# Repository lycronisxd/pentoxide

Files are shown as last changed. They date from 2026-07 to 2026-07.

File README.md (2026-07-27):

<h1 align="center">
  <picture>
  <source media="(prefers-color-scheme: dark)" srcset="https://github.com/user-attachments/assets/7219ccd8-d57b-41d6-96ce-b18b46f74935">
  <source media="(prefers-color-scheme: light)" srcset="https://github.com/user-attachments/assets/e426a1b6-aba4-4cd7-84bb-a8587f43f761">
  
  </picture>
</h1>

<h3 align="center">
  <picture>
  <source media="(prefers-color-scheme: dark)" srcset="https://github.com/user-attachments/assets/bf6074c8-e379-4ea4-a1d4-aef35d5d1d9c">
  <source media="(prefers-color-scheme: light)" srcset="https://github.com/user-attachments/assets/225eb73b-afd0-433c-afb1-c990a066f6d8">
  
  </picture>
  <div align="center">
    
  
  
  
  
  
  

  </div>
</h3>

<hr>

<!-- main body -->

<h3 align="center">
  <picture>
  <source media="(prefers-color-scheme: dark)" srcset="https://github.com/user-attachments/assets/0eb199f3-a66a-426e-8b88-3ce38c6fcc99">
  <source media="(prefers-color-scheme: light)" srcset="https://github.com/user-attachments/assets/3255cb05-ad44-49c5-b112-34e3b81043f4">
  
  </picture>
  <pre align="left">
pentoxide is an 18-key macro pad designed for creators and developers,
blending design language and function.
<br \>
built on top of QMK firmware with VIA compatibility,
pentoxide supports per-key rgb and a 128x160 1.8 inch lcd.
</pre>
</h3>

<hr>

<h3 align="center">
  <picture>
  <source media="(prefers-color-scheme: dark)" srcset="https://github.com/user-attachments/assets/8696bc60-909f-4c6e-ad67-8837299f265d">
  <source media="(prefers-color-scheme: light)" srcset="https://github.com/user-attachments/assets/cbb11c29-4aa7-4d3f-bdc8-6d2b004aac17">
  
  </picture>
<pre align="left">
{
"microcontroller": "raspberry-pi-rp2040",
"cpu-cores": "dual-core",
"clock-speed": "133-mhz",
"on-board-memory": "264-kb",
"gpio-pins": "30x",
"main-pcb": "pentoxide-mainboard",
"1u-mx-switches": "18x",
"switch-type": "everglide-aqua-king",
"rgb-capability": "y",
"rgb-leds": "18x",
"hotswap-capability": "y",
"kailh-hotswap-sockets": "18x",
"communication-sockets": "22x",
"display-size": "1.8-inch",
"display-resolution": "128x160",
"display-type": "tft-lcd",
"display-controller": "st7735s",
"firmware": "qmk",
"via-compatibility": "y"
}
</pre>
</h3>

<hr>

<h3 align="center">
  <picture>
  <source media="(prefers-color-scheme: dark)" srcset="https://github.com/user-attachments/assets/8fcd9fb2-011e-4284-a5a9-fb2776e90f1c">
  <source media="(prefers-color-scheme: light)" srcset="https://github.com/user-attachments/assets/7539e3ad-ad35-4bb8-8679-a545f65c9159">
  
  </picture>
  board image<br \>
  board image<br \>
  board image<br \>
  board image<br \>
  schematic<br \>
  kicad pcb image<br \>

</h3>

<hr>

<h3 align="center">
  <picture>
    <source media="(prefers-color-scheme: dark)" srcset="https://github.com/user-attachments/assets/2efd42f7-1078-4c4d-a306-e1f4fbedd322">
    <source media="(prefers-color-scheme: light)" srcset="https://github.com/user-attachments/assets/5ac018fb-4700-4111-8b4f-f1ed9c2d6f2b">
    
  </picture>
<pre align="left">
link to the public onshape project.
<a href="https://cad.onshape.com/documents/c17d4654dfdc64fa37b92d7c/w/b8eaedabc024b5a89ea703d7/e/db311653fe3b2444e14a3d99">https://pentoxide.onshape.com</a>
link to repo kicad files.
<a href="https://github.com/lycronisxd/pentoxide/tree/main/pcb">cd /root/pentoxide/pcb</a>
link to repo 3d printing files.
<a href="https://github.com/lycronisxd/pentoxide/tree/main/3dprinting">cd /root/pentoxide/3dprinting</a>
link to thingiverse 3d printing files.
<a href="https://www.thingiverse.com/thing:7385880">https://www.pentoxide.thingiverse.com</a>
</pre>
</h3>

<hr>

<h3 align="center">
  <picture>
  <source media="(prefers-color-scheme: dark)" srcset="https://github.com/user-attachments/assets/4b0244e2-1685-40e0-b2d2-98d43885c8d7">
  <source media="(prefers-color-scheme: light)" srcset="https://github.com/user-attachments/assets/0805ec88-f31b-448b-9def-bbe6aa447988">
  
  </picture>
  <pre align="left">
&lt!DOCTYPE html&gt
  &lthtml lang="en"&gt
    &lthead&gt
      &ltmeta charset="UTF-8"&gt
      &lttitle&gtrelevant links!&lt/title&gt
    &lt/head&gt
  &ltbody&gt
      &lth1&gthey there! below are some links to other projects that you can follow!&lt/h1&gt
      &lthr&gt
      &ltp&gt&lta href="https://github.com/lycronisxd/a-shift"&gt<a href="https://github.com/lycronisxd/a-shift">a-shift</a>&lt/a&gt&lt/p&gt
      &ltp&gt&lta href="https://github.com/lycronisxd/oxide-one"&gt<a href="https://github.com/lycronisxd/oxide-one">oxide-one</a>&lt/a&gt&lt/p&gt
      &ltp&gt&lta href="https://github.com/lycronisxd/ohm"&gt<a href="https://github.com/lycronisxd/ohm">ohm</a>&lt/a&gt&lt/p&gt
      &ltp&gt&lta href="https://github.com/lycronisxd/peroxide"&gt<a href="https://github.com/lycronisxd/peroxide">peroxide</a>&lt/a&gt&lt/p&gt
      &ltp&gt&lta href="https://github.com/lycronisxd/polylactic"&gt<a href="https://github.com/lycronisxd/polylactic">polylactic</a>&lt/a&gt&lt/p&gt
  &lt/body&gt
  &lt!--
  @@@@@@@@@@@@@@@@@@@@@@@@@@@@@@@@@@@@@@@@@@@@@@%#*************************************************#@@
  @@@@@@@@@@@@@@@@@@@@@@@@@@@@@@@@@@@@@@@@@%#%@@=.                    ..*#+         +#*.           =%@
  @@@@@@@@@@@@@@@@@@@@@@@@@@@@@@@@@@@@@@@@%+.=%@=.                    ..--:         *@%.           =%@
  @@@@@#-=+-:::-%@@@@#-:::-*@@@=:#=:::-*@#-...:+=.:+#%%#*-..-*#=. .+##..*#+  .+#%%#*#@%. .:*#%%#=..=%@
  @@@@@*..-#%%+:.+@@-.=%%%=.=%@-..*%%*.:*@#=.=#%=+%@-:.-*@*:.:#@#-#@*...#@* -#@*-::+@@%..+@#:.:+%#:=%@
  @@@@@*.:#@@@@+..%*..====-:.*@-.+@@@%:.+@%+.=%@*%@-   .:%%=  .+%@@:. ..#@*.=@#:.  .*@%.-@%#****%@==%@
  @@@@#-%%-   .+%%.+@%.........#@+.  .%%+ .+@*. =..*@@@@#:.+@@%-...:@@@%:.=@+ -#@@@@= :@#.:#@@@@@@@@@@
  @@@@#-%@%-..+%@+..%@#...+@%-.#@+.  .%%+ .+@#:.++..#@@#-.-%@*:.*@=..#@%:.=@%-.-#%%=. :@%=.-%@@*::#@@@
  @@@@#-%%**%%%*:.  .-#%%%#=. .*#=.  .##+ .:*%%**%%+::::-#@@+:-#@@@#::+%=:+@@@*-:::+*:-@@@#=::::*%@@@@
  @@@@#-%%-                                     +%@@@@@@@@@@@@@@@@@@@@@@@@@@@@@@@@@@@@@@@@@@@@@@@@@@@@
  @@@@#-**-                                     +%@@@@@@@@@@@@@@@@@@@@@@@@@@@@@@@@@@@@@@@@@@@@@@@@@@@@
  @@@@@%%%%%%%%%%%%%%%%%%%%%%%%%%%%%%%%%%%%%%%%%@@@@@@@@@@@@@@@@@@@@@@@@@@@@@@@@@@@@@@@@@@@@@@@@@@@@@@
  --&gt
</pre>
</h3>
  
<hr>

<h3 align="center">

  <picture>
  <source media="(prefers-color-scheme: dark)" srcset="https://github.com/user-attachments/assets/031f2031-ec8b-4581-bf83-9b06f5faa409">
  <source media="(prefers-color-scheme: light)" srcset="https://github.com/user-attachments/assets/4cdb615e-4db5-4dbc-abcc-0074ae9797d5">
  
  </picture>
</h3>

| item no. | part no. | part name | qty. | supplier | unit cost | total cost | notes |
|---|---|---|----:|---|---:|---:|---|
| 1 | PCB-001 | pentoxide-pcb | 1 | jlcpcb | $11.90 | $11.90 | - |
| 2 | PCB-002 | 0805-100nf-cap | 18 | aliexpress | $0.04 | $3.62 | 100 pcs was the smallest i could find. |
| 3 | PCB-003 | 0805-330-res | 1 | aliexpress | $2.64 | $2.64 | - |
| 4 | PCB-004 | sod-123-1n4148w | 18 | aliexpress | $0.02 | $1.53 | 100 pcs was the smallest i could find. |
| 5 | PCB-005 | kailh-hs-socket | 18 | aliexpress | $0.22 | $6.66 | 30 pcs was the smallest i could find. |
| 6 | PCB-006 | sk6812-mini-e-led | 18 | aliexpress | $0.08 | $4.09 | 50 pcs was the smallest i could find. |
| 7 | PCB-007 | 128x160-lcd | 1 | aliexpress | $3.82 | $3.82 | - |
| 8 | PCB-008 | rp2040-pro-micro | 1 | aliexpress | $3.79 | $3.79 | - |
| 9 | SW-001 | mmd-aqua-king | 18 | aliexpress | $0.53 | $15.81 | 30 pcs was the smallest i could find. |
| 10 | SW-002 | cherry-keycap | 18 | aliexpress | $0.30 | $5.91 | 20 pcs was the smallest i could find. |
| 11 | MNT-001 | m4-bolt | 10 | aliexpress | $8.97 | $8.97 | see notes below. |
| 12 | MNT-002 | m2-bolt | 4 | aliexpress | - | - | price included in M4 bolt price. |
| 13 | MNT-003 | m2-nut | 4 | aliexpress | - | - | price included in M4 bolt price. |
| 14 | MNT-004 | m4-insert | 10 | aliexpress | $0.04 | $4.02 | 100 pcs was the smallest i could find. |
| 15 | 3D-001 | pentoxide-plate | 1 | N/A | - | - | custom print / print legion. |
| 16 | 3D-002 | pentoxide-case | 1 | N/A | - | - | custom print / print legion. |

<br />
<b>total cost : 72.76 USD (54.24 GBP)</b>
<hr>

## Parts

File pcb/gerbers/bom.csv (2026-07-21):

Designator | Footprint | Quantity | Value | LCSC Part #
C1, C10, C11, C12, C13, C14, C17, C18, C19, C2, C20, C3, C4, C5, C6, C7, C8, C9 | 805 | 18 | 0.1uF | C14663
D1, D10, D11, D12, D13, D14, D17, D18, D19, D2, D20, D3, D4, D5, D6, D7, D8, D9 | D_SOD-123 | 18 | D_Small | C241939
D21, D22, D23, D24, D25, D26, D27, D28, D29, D30, D31, D32, D33, D34, D37, D38, D39, D40 | LED_SK6812MINI-E_3.2x2.8mm_P1.5mm_ReverseMount | 18 | SK6812MINI-E | C5149201
J2 | PinHeader_2x11_P2.54mm_Vertical | 1 | DNP
R1 | 805 | 1 | 330 | C2907002
SW1, SW10, SW11, SW12, SW13, SW14, SW17, SW18, SW19, SW2, SW20, SW3, SW4, SW5, SW6, SW7, SW8, SW9 | MX-Hotswap-1U | 18 | SW_Push | C49352235

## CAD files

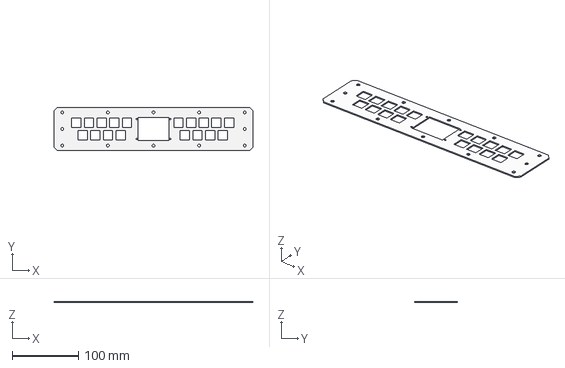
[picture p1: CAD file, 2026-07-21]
3dprinting/plate.step
300.0 x 65.0 x 1.50 mm

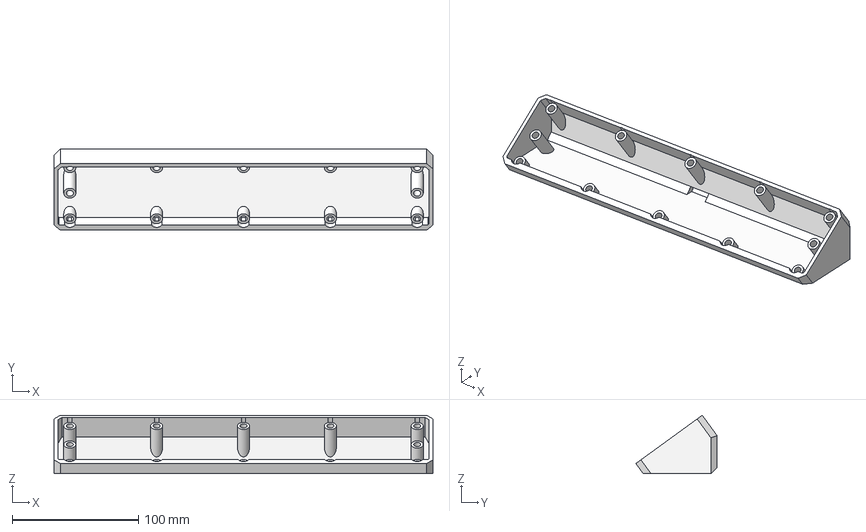
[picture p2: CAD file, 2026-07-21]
3dprinting/case.step
300.0 x 64.3 x 46.3 mm

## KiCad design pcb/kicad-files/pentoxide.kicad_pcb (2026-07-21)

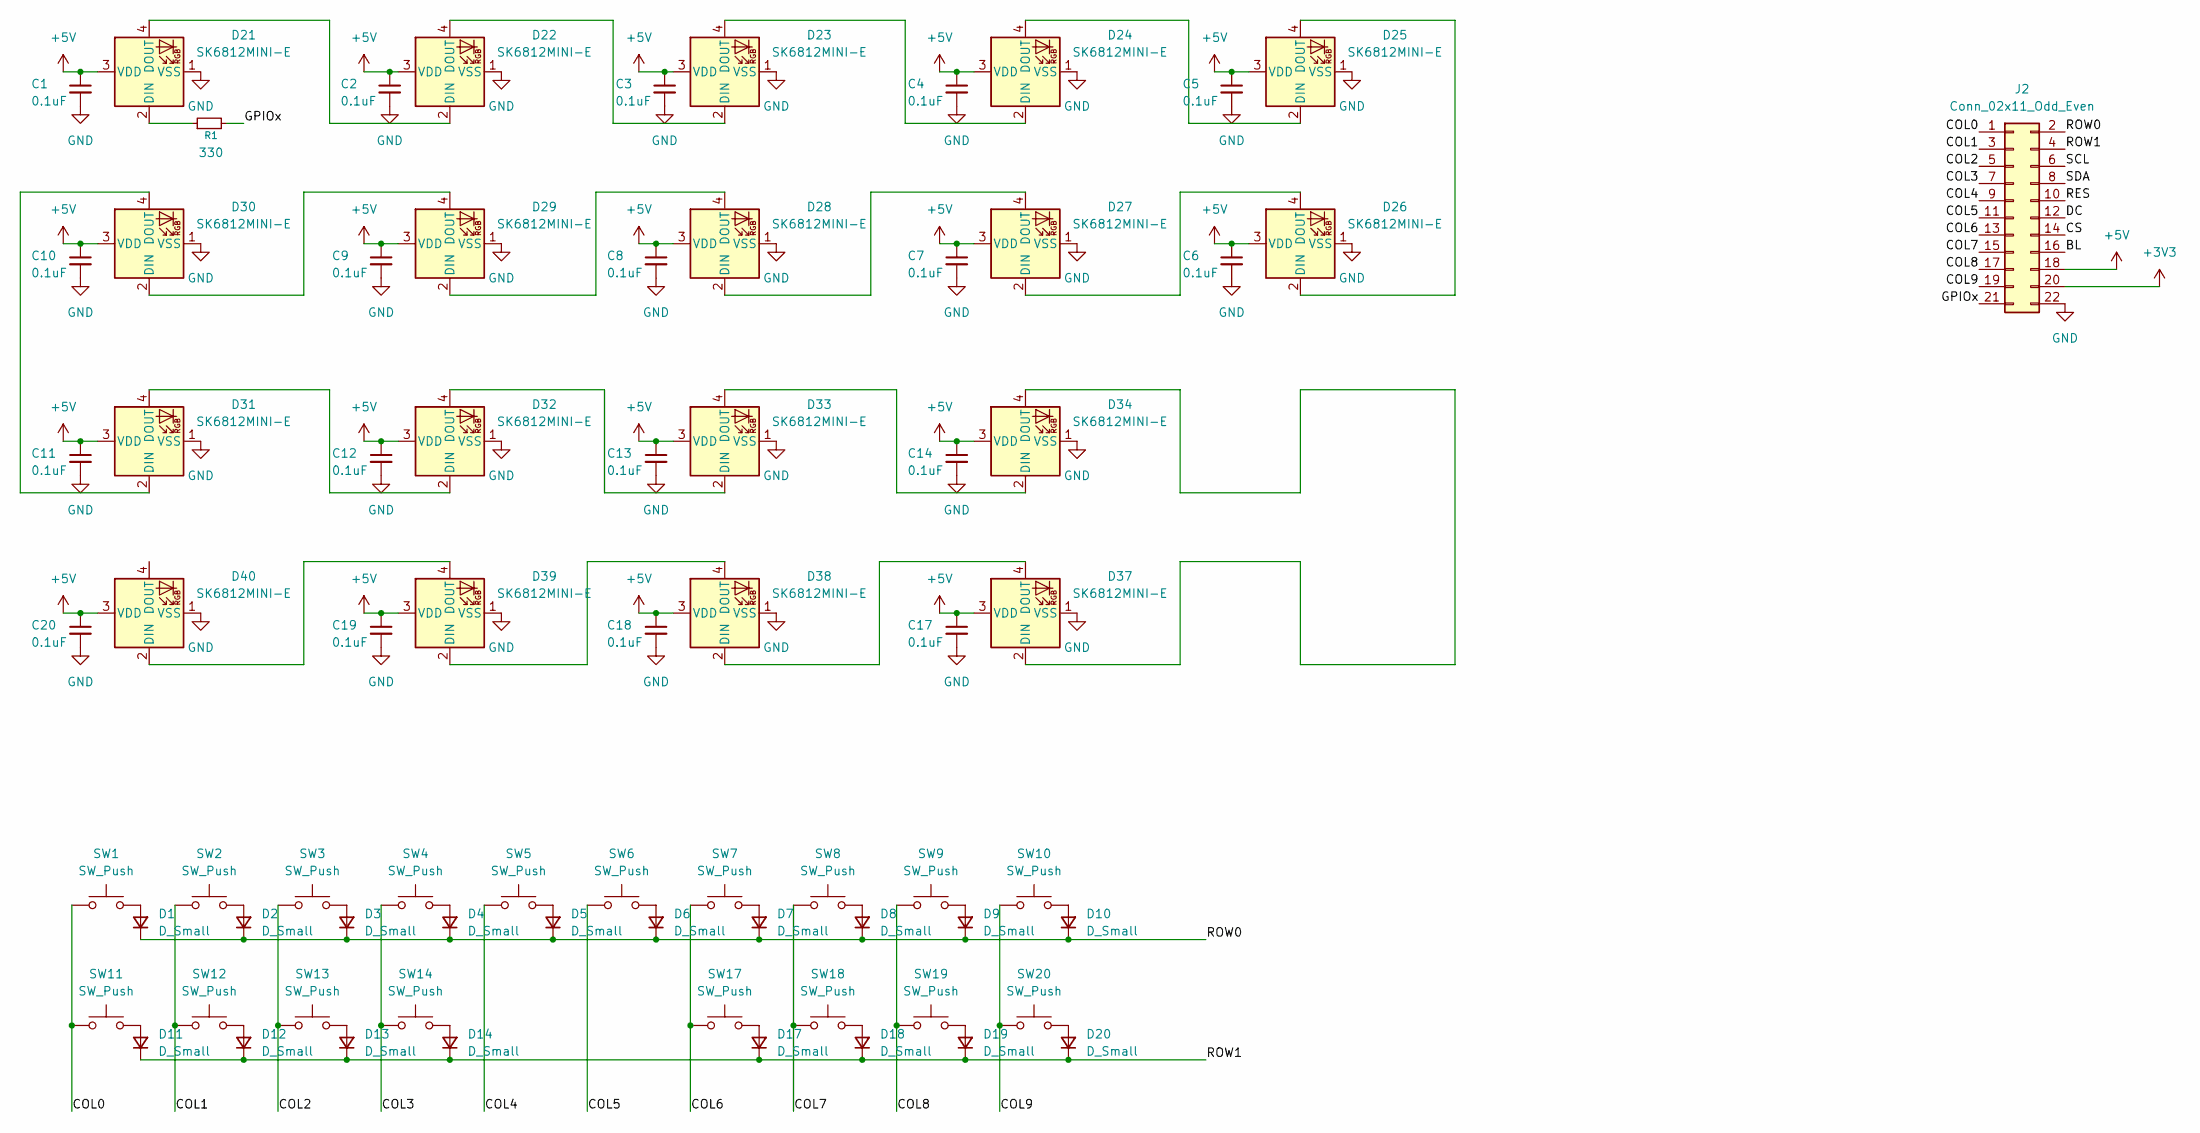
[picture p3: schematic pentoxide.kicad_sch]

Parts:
C1, C2, C3, C4, C5, C6, C7, C8, C9, C10, C11, C12, C13, C14, C17, C18, C19, C20: 0.1uF; C_0805_2012Metric_Pad1.18x1.45mm_HandSolder
D1, D2, D3, D4, D5, D6, D7, D8, D9, D10, D11, D12, D13, D14, D17, D18, D19, D20: D_Small; D_SOD-123
D21, D22, D23, D24, D25, D26, D27, D28, D29, D30, D31, D32, D33, D34, D37, D38, D39, D40: SK6812MINI-E; LED_SK6812MINI-E_3.2x2.8mm_P1.5mm_ReverseMount
J2: Conn_02x11_Odd_Even; PinHeader_2x11_P2.54mm_Vertical
R1: 330; R_0805_2012Metric_Pad1.20x1.40mm_HandSolder
SW1, SW2, SW3, SW4, SW5, SW6, SW7, SW8, SW9, SW10, SW11, SW12, SW13, SW14, SW17, SW18, SW19, SW20: SW_Push; MX-Hotswap-1U

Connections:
+3V3: J2.20
+5V: C1.1, C2.1, C3.1, C4.1, C5.1, C6.1, C7.1, C8.1, C9.1, C10.1, C11.1, C12.1, C13.1, C14.1, C17.1, C18.1, C19.1, C20.1, D21.3 (VDD), D22.3 (VDD), D23.3 (VDD), D24.3 (VDD), D25.3 (VDD), D26.3 (VDD), D27.3 (VDD), D28.3 (VDD), D29.3 (VDD), D30.3 (VDD), D31.3 (VDD), D32.3 (VDD), D33.3 (VDD), D34.3 (VDD), D37.3 (VDD), D38.3 (VDD), D39.3 (VDD), D40.3 (VDD), J2.18
/BL: J2.16
/COL0: J2.1, SW1.1, SW11.1
/COL1: J2.3, SW2.1, SW12.1
/COL2: J2.5, SW3.1, SW13.1
/COL3: J2.7, SW4.1, SW14.1
/COL4: J2.9, SW5.1
/COL5: J2.11, SW6.1
/COL6: J2.13, SW7.1, SW17.1
/COL7: J2.15, SW8.1, SW18.1
/COL8: J2.17, SW9.1, SW19.1
/COL9: J2.19, SW10.1, SW20.1
/CS: J2.14
/DC: J2.12
/GPIOx: J2.21, R1.2
/RES: J2.10
/ROW0: D1.1 (K), D2.1 (K), D3.1 (K), D4.1 (K), D5.1 (K), D6.1 (K), D7.1 (K), D8.1 (K), D9.1 (K), D10.1 (K), J2.2
/ROW1: D11.1 (K), D12.1 (K), D13.1 (K), D14.1 (K), D17.1 (K), D18.1 (K), D19.1 (K), D20.1 (K), J2.4
/SCL: J2.6
/SDA: J2.8
GND: C1.2, C2.2, C3.2, C4.2, C5.2, C6.2, C7.2, C8.2, C9.2, C10.2, C11.2, C12.2, C13.2, C14.2, C17.2, C18.2, C19.2, C20.2, D21.1 (VSS), D22.1 (VSS), D23.1 (VSS), D24.1 (VSS), D25.1 (VSS), D26.1 (VSS), D27.1 (VSS), D28.1 (VSS), D29.1 (VSS), D30.1 (VSS), D31.1 (VSS), D32.1 (VSS), D33.1 (VSS), D34.1 (VSS), D37.1 (VSS), D38.1 (VSS), D39.1 (VSS), D40.1 (VSS), J2.22
unnamed: D1.2 (A), SW1.2
unnamed: D2.2 (A), SW2.2
unnamed: D3.2 (A), SW3.2
unnamed: D4.2 (A), SW4.2
unnamed: D5.2 (A), SW5.2
unnamed: D6.2 (A), SW6.2
unnamed: D7.2 (A), SW7.2
unnamed: D8.2 (A), SW8.2
unnamed: D9.2 (A), SW9.2
unnamed: D10.2 (A), SW10.2
unnamed: D11.2 (A), SW11.2
unnamed: D12.2 (A), SW12.2
unnamed: D13.2 (A), SW13.2
unnamed: D14.2 (A), SW14.2
unnamed: D17.2 (A), SW17.2
unnamed: D18.2 (A), SW18.2
unnamed: D19.2 (A), SW19.2
unnamed: D20.2 (A), SW20.2
unnamed: D21.2 (DIN), R1.1
unnamed: D21.4 (DOUT), D22.2 (DIN)
unnamed: D22.4 (DOUT), D23.2 (DIN)
unnamed: D23.4 (DOUT), D24.2 (DIN)
unnamed: D24.4 (DOUT), D25.2 (DIN)
unnamed: D25.4 (DOUT), D26.2 (DIN)
unnamed: D26.4 (DOUT), D27.2 (DIN)
unnamed: D27.4 (DOUT), D28.2 (DIN)
unnamed: D28.4 (DOUT), D29.2 (DIN)
unnamed: D29.4 (DOUT), D30.2 (DIN)
unnamed: D30.4 (DOUT), D31.2 (DIN)
unnamed: D31.4 (DOUT), D32.2 (DIN)
unnamed: D32.4 (DOUT), D33.2 (DIN)
unnamed: D33.4 (DOUT), D34.2 (DIN)
unnamed: D34.4 (DOUT), D37.2 (DIN)
unnamed: D37.4 (DOUT), D38.2 (DIN)
unnamed: D38.4 (DOUT), D39.2 (DIN)
unnamed: D39.4 (DOUT), D40.2 (DIN)

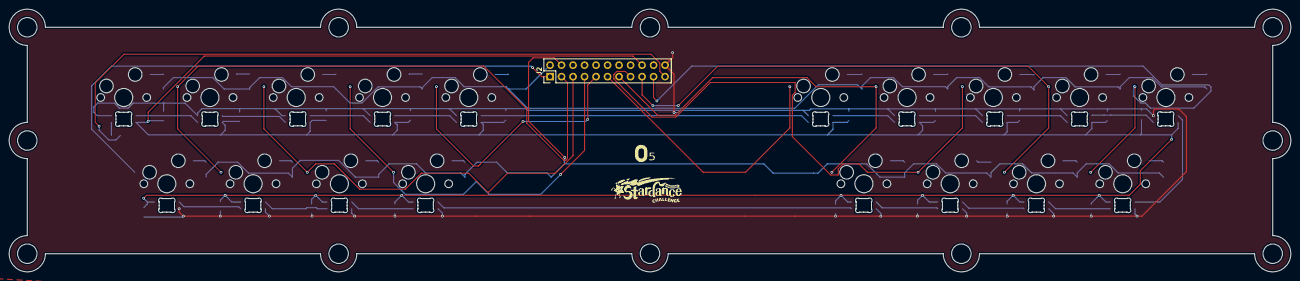
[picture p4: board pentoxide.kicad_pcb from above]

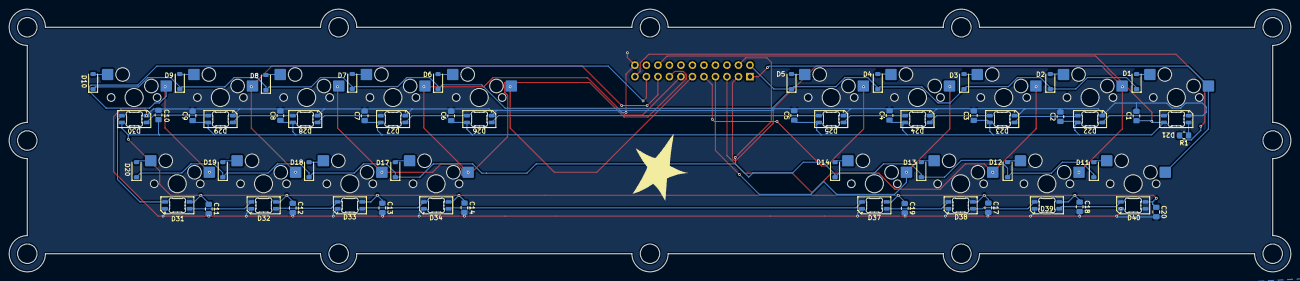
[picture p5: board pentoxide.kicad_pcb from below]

Board: 2 copper layers, 283.0 x 58.0 mm, 74 parts (55 on the bottom side), 51 nets.

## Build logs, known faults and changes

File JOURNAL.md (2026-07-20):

<h3>entry 1, 19/07/26 : 12:31 - 13:33</h3>
before starting pcb design, i hopped on excalidraw to try and make a layout that would be good to use.<br \>
<br \>
i first created the keyboard schematic since i already know how to wire a keyboard matrix.<br \>
<br \>
i then researched the type of leds that i want to use in the keyboard.<br \>
turns out sk6812mini-e's are a standard led that are supported by qmk - so i decided to use those<br \>
looked for a pinout online and wired everything up.<br \>
<br \>
i decided not to hook any gpio pins up yet, because i want to make the connections as clean as possible.<br \>
i then found a 1.8 inch lcd screen that i want to build around, so i found the pinout for that and wired it up.<br \>
<br \>
finally, i assigned footprints to each of the components, and am ready to begin pcb routing!<br \>
and here is the final schematic!<br \>
<br \>
<br \>
<b>entry time - 1 hour 2 minutes</b><br \>
<b>total time - 1 hour 2 minutes</b>
<hr>
<h3>entry 2, 19/07/26 : 13:35 - 14:58</h3>
this ENTIRE TIME was spent placing components, routing traces and making a board, because there are so many components to be placed and its going to be hell soldering all of them :)<br \>
<br \>
<br \>
<br \>
<b>entry time - 1 hour 23 minutes</b><br \>
<b>total time - 2 hours 25 minutes</b>
<hr>
<h3>entry 3, 20/07/26 : 11:10 - 14:06</h3>
strap in! i spent a lot of time in this session locked in!<br \>
so, i first started by downloading the 3d model of the (old) pcb from kicad so i could insert into a new onshape project<br \>
<br \>
i then went on grabcad and found a 3d model of a 128x160 lcd that i could find easily on aliexpress and i found this!<br \>
<br \>
but i was unsure of the clearance between the screen and switches - and i found out that the switches clipped the display.<br \>
so i spent some time on kicad removing one of the switches on each side so now theres 18 macro keys instead of 20!<br \>
<br \>
<br \>
so, once that was fixed - i made a plate to house the keys and display!<br \>
<br \>
and then after i put everything into place in the main assembly, i designed a case around the plate. (note. the big mounting holes are for m4 inserts to hold the pcb and plate in place)<br \>
<br \>
and then, i got a cherry mx switch model from grabcad, bolts from onshape's content library, and put everything together in the main assembly - and it looked like this. ugly right?<br \>
<br \>
so i changed the colours up a bit and added cherry profile keycaps i found on grabcad and voila, the final product!<br \>
<br \>
<br \>
<b>entry time - 2 hours 56 minutes</b><br \>
<b>total time - 5 hours 21 minutes</b>
<hr>
<h3>entry 4, 20/07/26 : 14:14 - 17:09</h3>
the entire time was spent figuring out rendering and editing, so enjoy! <br \>
got really inspired by the style of watchdogs 2 as i was editing them - so hopefully some can recognize it!<br \>
<br \>
<br \>
<br \>
<br \>
<br \>
<br \>
<br \>
<br \>
<br \>
<br \>
<b>entry time - 2 hours 55 minutes</b><br \>
<b>total time - 8 hours 16 minutes</b>
<hr>

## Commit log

2026-07-21 update README.md with proper image scaling for all devices
2026-07-21 finish about and begin cad links in README.md
2026-07-21 create kicad folder
2026-07-21 add case and plate to 3dprinting folder
    [case.step, plate.step]
2026-07-21 create pcb folder
2026-07-21 create pcb/kicad-files folder
2026-07-21 upload kicad files to pcb/kicad-files
    [pentoxide.kicad_pcb, pentoxide.kicad_sch]
2026-07-21 create pcb/gerbers folder
2026-07-21 update kicad project files in pcb/kicad-files
    [pentoxide.kicad_pcb, pentoxide.kicad_sch]
2026-07-21 added jlcpcb production files in pcb/gerbers
    [bom.csv, designators.csv, positions.csv]
2026-07-21 complete cad file links in README.md
2026-07-21 update bom in README.md
2026-07-26 add schematic and kicad files to README.md
